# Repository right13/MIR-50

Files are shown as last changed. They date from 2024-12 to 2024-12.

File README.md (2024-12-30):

I re-designed back in 2012 and old amplifier design published in one of the local magazines for radio amateurs in 1992. The goal was to adapt it to modern (back in 2012) semiconductors and redesign the PCB for DIY audio community in the country.
There is not too much description: I couldnt find the original text. 
 I, with a few other guys managed to sell a few hundreds pcs of the kit and also I made probably another 100 pcs at home by myself. It works as a charm after first powering. Some guys used it as headphone amplifier. 

Some parameters:
Power transistors : TOSHIBA 2SC5200/2SA1943
 Exciters : 2SA1837/2CS4792 or 2SA1930/2SC5171
Pre-amplifier : BD139/140 
Differential stage : BC550/560
Power supply : 2x30V DC 4R 
Output power : 56W
Minimum load impedance : 4R Input sensitivity 
: approx. 1 -1.3V@56W SR waveform speed : 52V/us
Fuses : F2,5A 
Dimension - 130x115 mm
Quiescent current on fuses approx. 120mA (on emitter resistors approx. 13-26mV)

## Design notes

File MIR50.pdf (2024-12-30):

## Nízkofrekvenčný tranzistorový zosilňovač

# MIR50

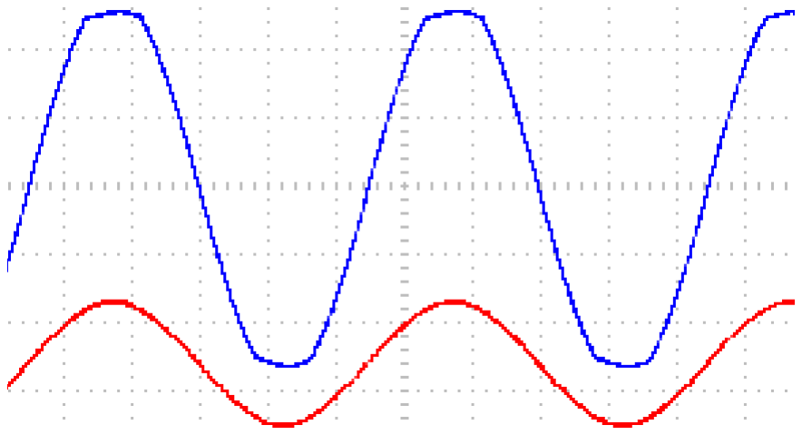
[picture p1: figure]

Autor pôvodného zapojenia : Pavel Dudek

Technický poradca úprav : Bc.Robert Kovář

Autor DPS a realizátor : Martin Krchňák

Distribúcia DPS a doplnkov : Petr Matušek

### Popis

Schéma zapojenia vychádza zo zapojenia DPA110 ktoré navrhol pán Dudek . V pôvodnom zapojení sú použité súčiastky dostupné v dobe vzniku, no na dnešnú dobu zastaralé a zle dostupné. Zapojenie MIR50 je prispôsobené na moderné bežne dostupné súčiastky s lepšími parametrami, čím sa podarilo dosiahnuť výborné výsledky po elektrickej aj po zvukovej stránke .

Tento dokument je príloha ku zakúpeným DPS .

Osadenie

Koncové tranzistory : TOSHIBA 2SC5200/2SA1943

Budiče : 2SA1837/2CS4792 alebo 2SA1930/2SC5171

Predbudič a rozkmit : BD139/140

Diferenčný stupeň : BC550/560

Parametre

Napájanie : 2x30V DC

Výstupný výkon 4R : 56W

Minimálna zaťažovacia impedancia : 4R

Vstupná citlivosť : cca 1 ‐1,3V@56W

Rýchlosť priebehu SR : 52V/us

Poistky : F2,5A

Rozmer ‐ 130x115 mm

### Zoznam súčiastok

Rezistory

4 | 0R | R, R67, R74, R75
12 | 1R/1W | R42, R43①, R44, R45,
| | R46, R47①, R48, R49, R61, R62, R54, R55
2 | 4R7/2W | R59, R60
9 | 10R | R12③, R50②, R56②, R57②, R58②.
| | R52, R53, R68, R69
4 | 39R | R27, R28, R33, R34
2 | 47R | R40, R41
9 | 100R | R3, R4, R5, R6, R32, R15, R16, R29, R51
2 | 150R | R37, R38
6 | 220R | R19, R20, R24, R39, R63, R23
1 | 470R | R13
1 | 680R | R31
2 | 1k | R17, R18
1 | 1k2 | R1
2 | 1K5 | R9, R10
3 | 1k8 | R30, R35, R36
4 | 2k2 | R7, R8, R21, R22
1 | 3k3 | R11
2 | 11k | R25, R25
2 | 47k | R2, R26
1 | 1M | R14
1 | T67W-5K | P2
1 | T67W-50K | P1

Polovodiče

1 | 2SA1943 | U$1
1 | 2SC5200 | U$2
1 | 2SA1837 | T21
1 | 2SC4793 | T25
2 | 4V7 /1,3W zenerová dioda | D7, D8
2 | 15V /1,3W zenerová dioda | D1, D2
4 | BAV21 | D3, D5, D9, D10
2 | 1N4148 | D11, D12
5 | BC546 | T1, T2, T3, T7, T13
5 | BC556 | T4, T5, T6, T8, T14
1 | BC558 | T12
3 | BD139 | T10, T11, T15
2 | BD140 | T9, T16
2 | BY299 | D20, D21
2 | červená 5mm | LED1, LED2

Kondenzátory

3 | 1µF | | C1, C16, C22
2 | 1nF | | C8, C9
2 | 2p7 | | C10, C11
2 | 10nF | | C17, C18
2 | 22pF⑤ | | C25, C26
2 | 47nF | 10mm | C19, C20
10 | 100nF | | C3, C24, C27, C29, C31, C32, C33, C34, C35, C15
8 | 100uF/50V | | C6, C7, C12, C13, C19, C21, C23, C30
2 | 100uF/25V | | C4, C5
1 | 220pF | | C2
1 | 2p7/3p3④

*pokial nie je napísané ináč C majú raster 5mm

Mechanické prvky

1 | PSH02-02P | K1
6 | faston ST4,8 | X1, X2, X3, X4, X5, X6
2 | 2,5A | F1, F2

Pozn.

① neosadzovať ,v emitoroch použiť iba 4ks 1R/1W

②Osadiť buď 4x 10R/1W alebo 2x4R7/2W

③Možné nahradiť prepojkou

④Osadiť podla budičov, pre 2SA1837/4793 použiť 2p7 , pre 2SA1930/2SC5171 3p3

⑤Osadiť v prípade nestability

### Schéma zapojenia

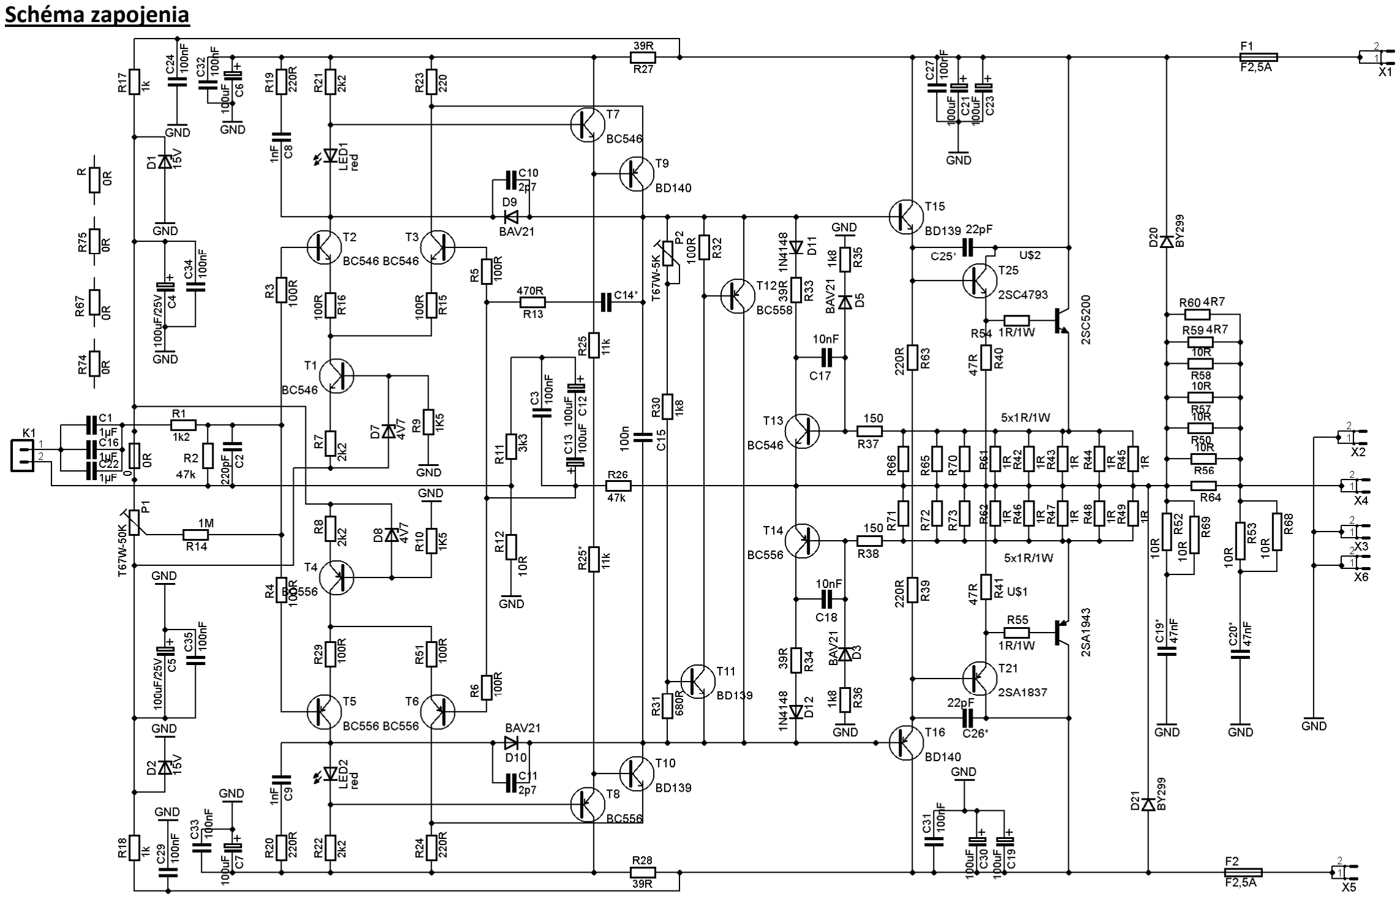
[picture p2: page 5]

### Osadzovací plán

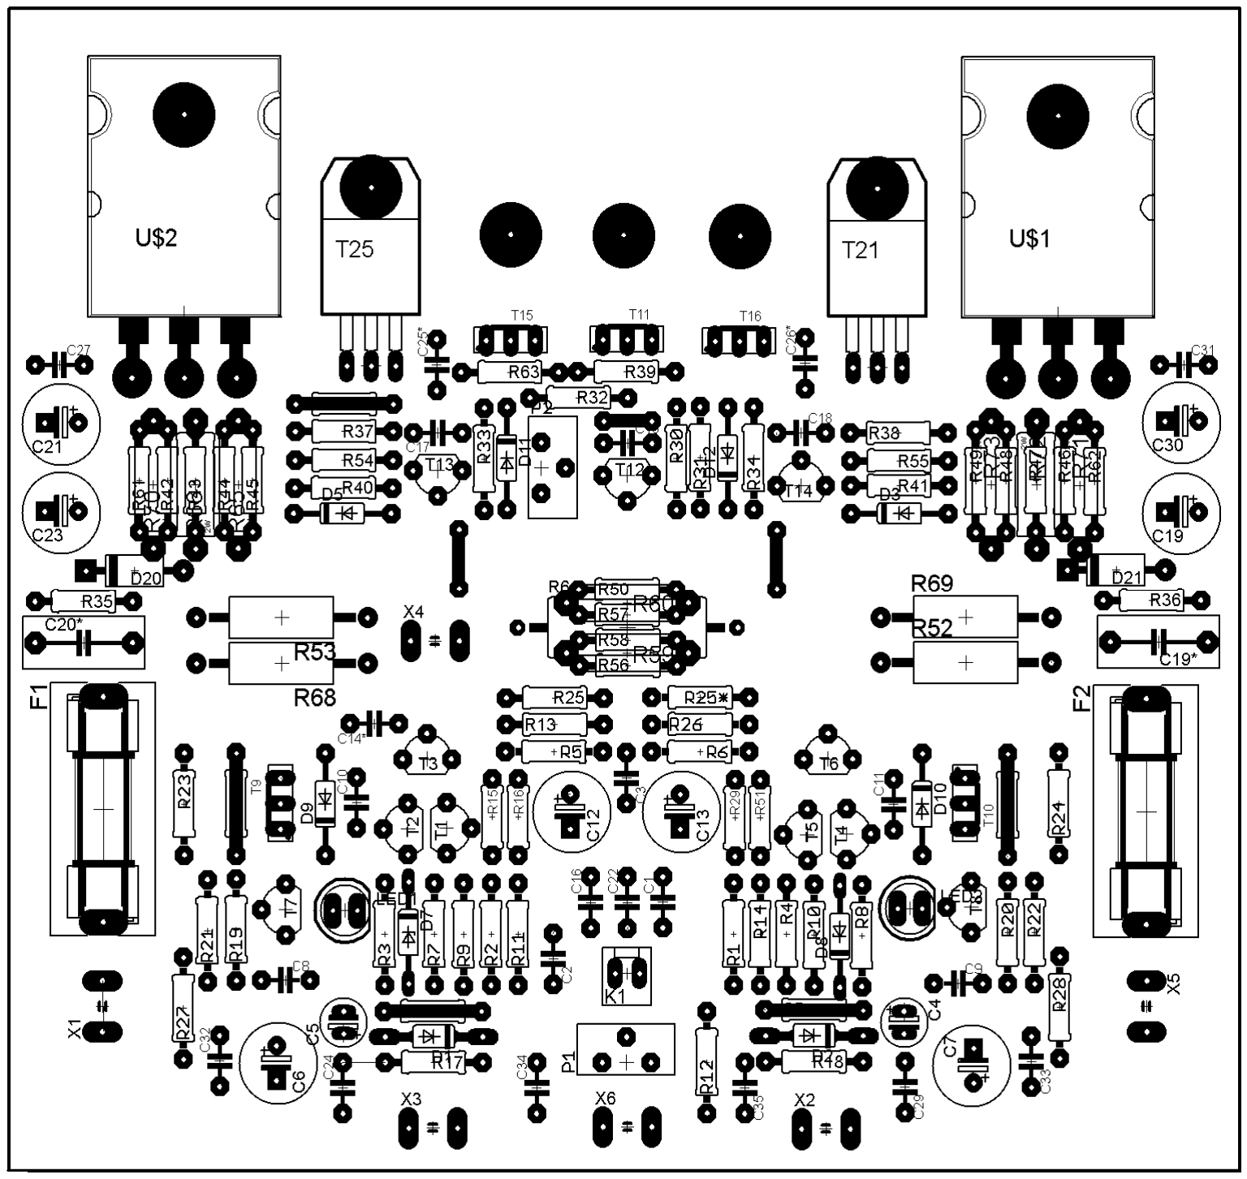
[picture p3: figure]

### Výkres AL profilu

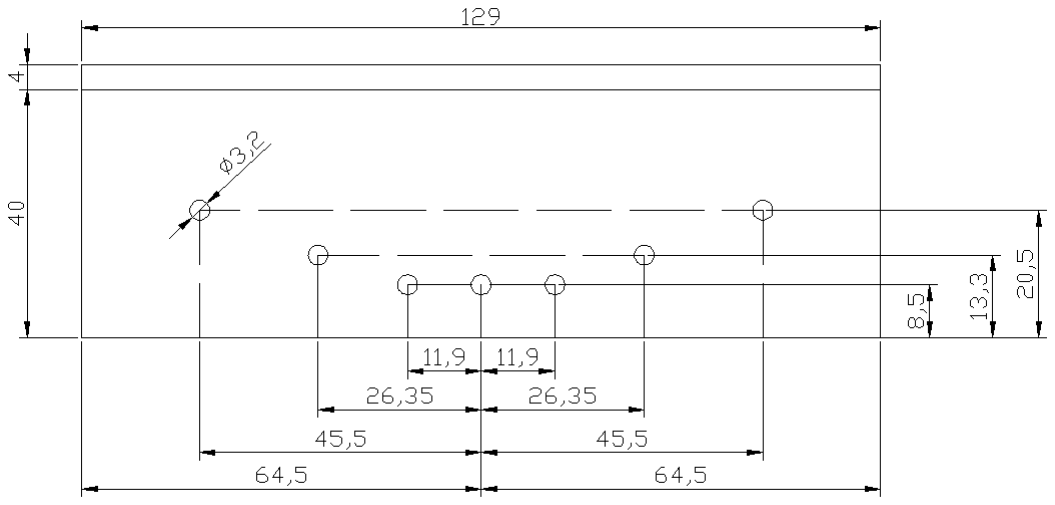
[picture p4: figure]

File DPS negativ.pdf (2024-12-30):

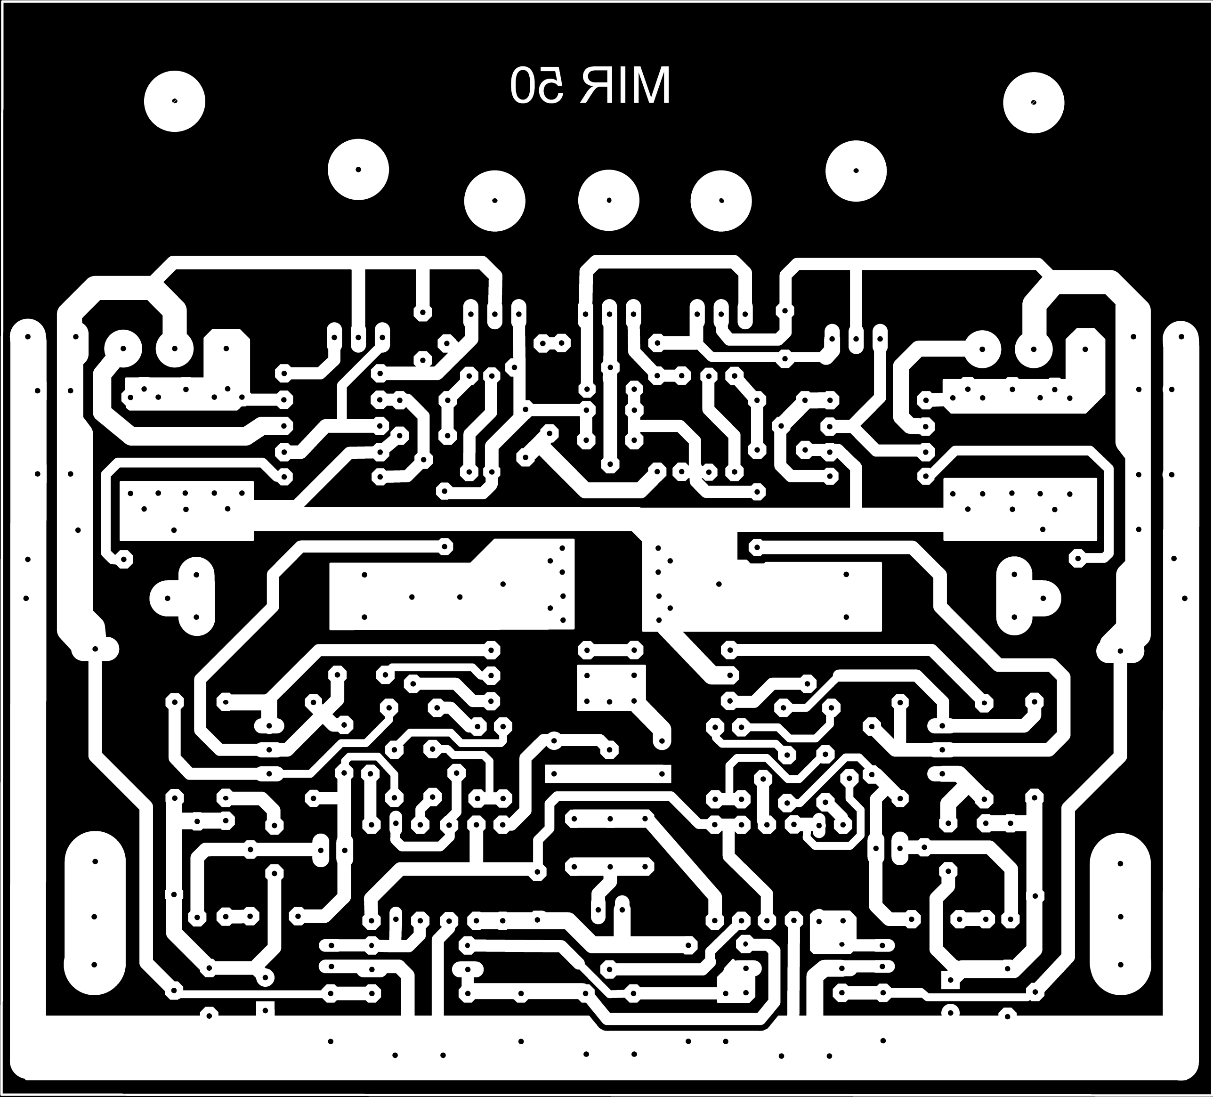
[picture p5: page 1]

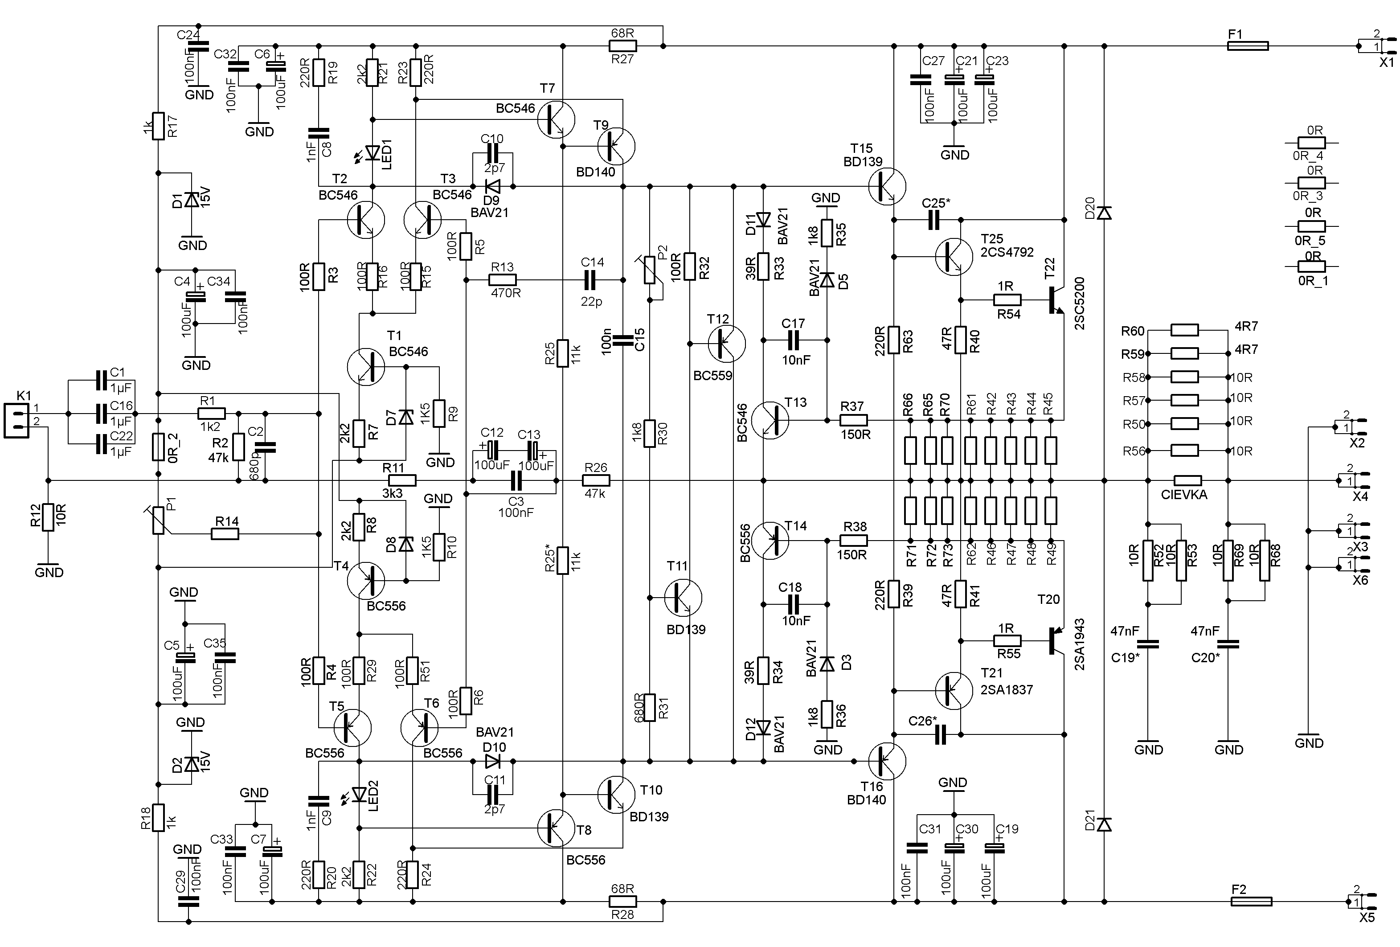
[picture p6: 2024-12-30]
schema.png

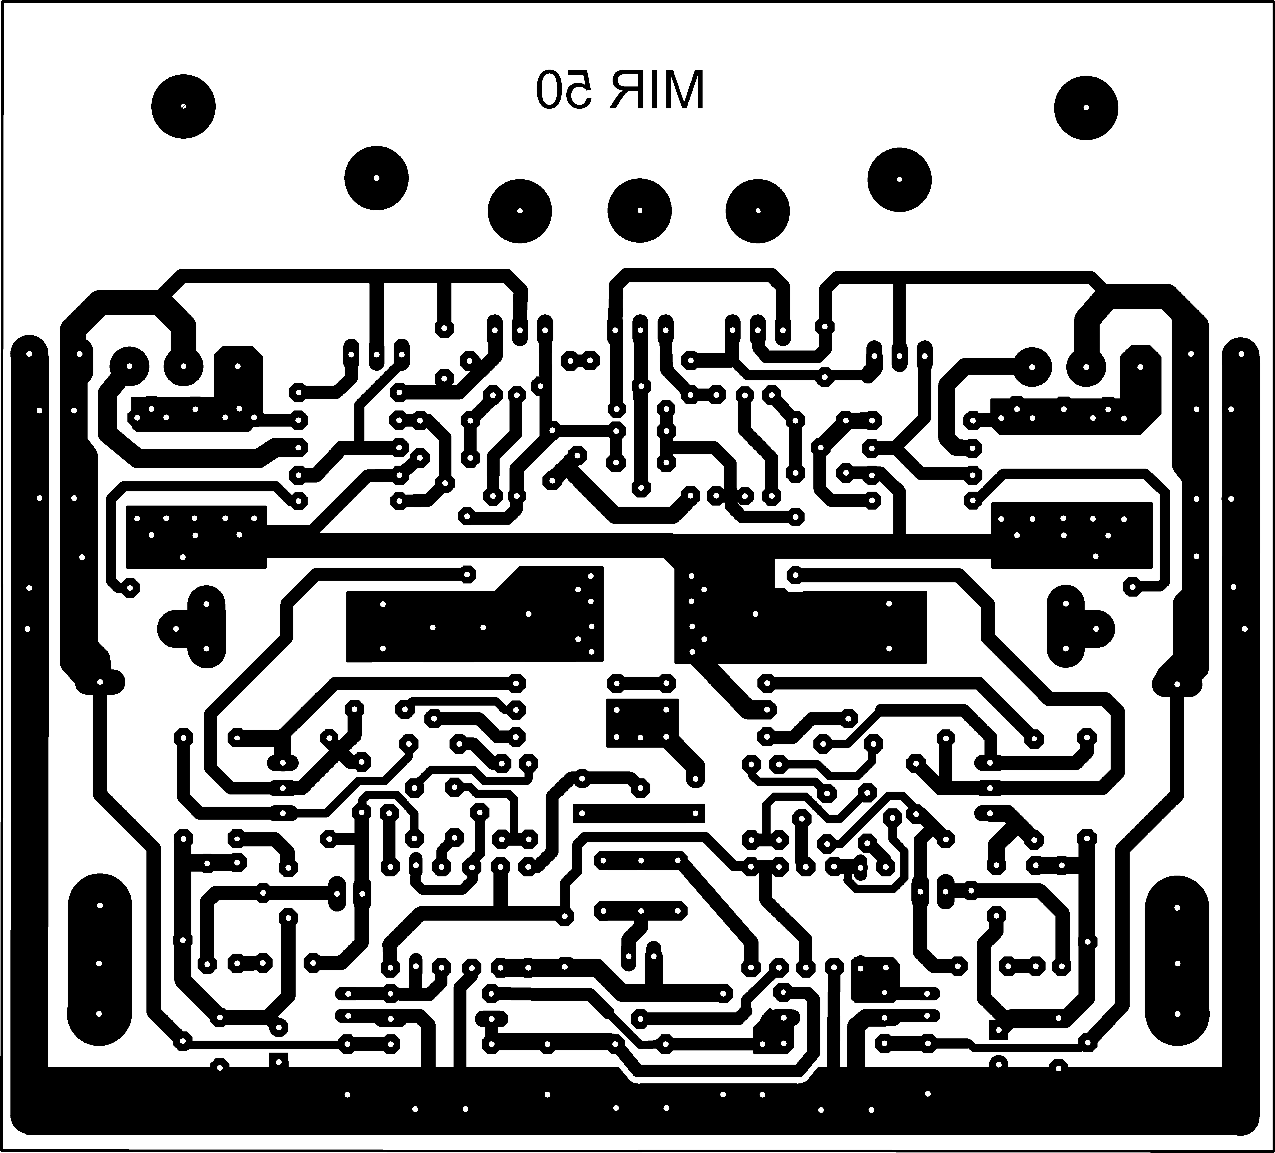
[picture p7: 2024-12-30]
DPS pozitiv.png

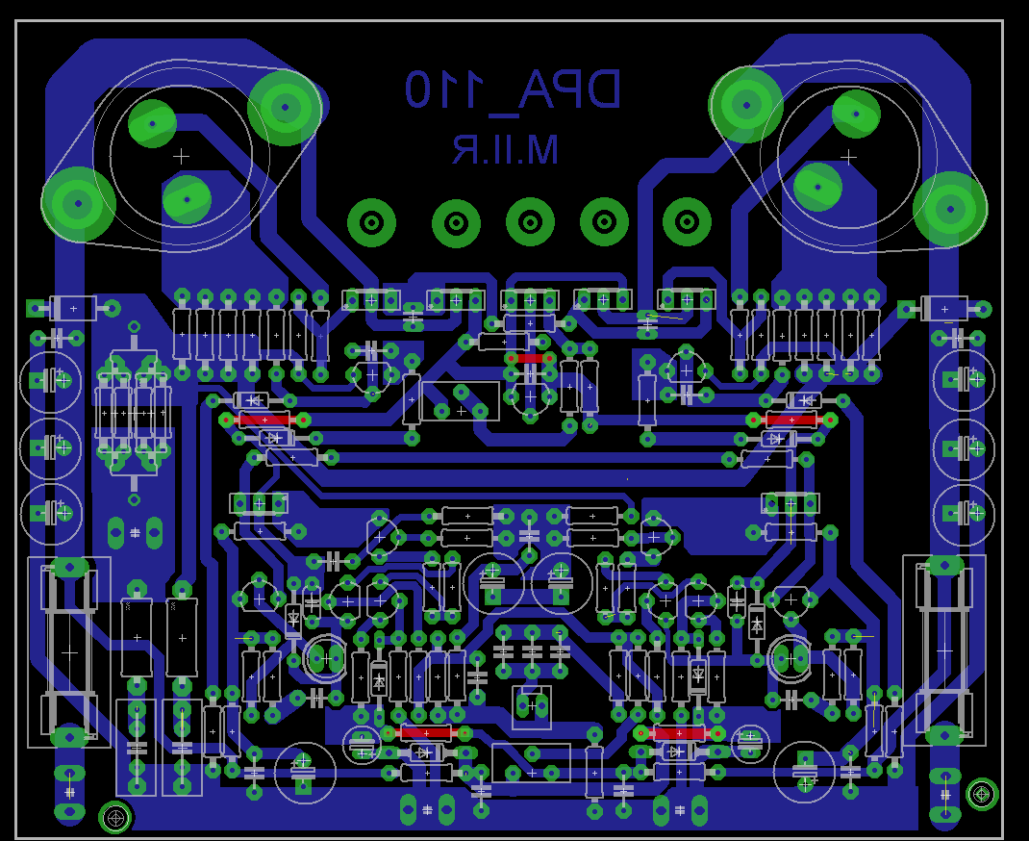
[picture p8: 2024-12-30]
board.png

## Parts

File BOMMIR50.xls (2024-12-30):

 | No | Value | Resistors
Qty Value Device Parts | 1 | PSH02-02P | 5 | 0R
1 PSH02-02P K1 | 1 | CIEVKA | 2 | 1K5
1 R-EU_0617/22 CIEVKA | 6 | faston 4,8 + fastin | 1 | 1M
6 R__2W R65, R66, R70, R71, R72, R73 | 2x fuse holder |  | 2 | 1k
6 ST4,8 X1, X2, X3, X4, X5, X6 |  |  | 1 | 1k2
1 0 R_10 0R |  |  | 3 | 1k8
4 0R R_10 R, R67, R74, R75 | semiconductors |  | 1 | 3k3
3 1µF C-KERAMIK_5 C1, C16, C22 | 2 | F2,5A-poistka | 2 | 11k
2 1K5 R_10 R9, R10 | 1 | 2SA1837 | 2 | 22R
1 1M R_10 R14 | 1 | 2SA1943 | 2 | 39R
10 1R R_10 R42, R43, R44, R45, R46, R47, R48, R49, R61, R62 | 1 | 2SC4793 | 2 | 47R
2 1R/1W R_10 R54, R55 | 1 | 2SC5200 | 2 | 47k
2 1k R_10 R17, R18 | 2 | 4V7 ZD | 9 | 100R
1 1k2 R_10 R1 | 2 | 15V-ZD | 2 | 150R
3 1k8 R_10 R30, R35, R36 | 6 | BAV21 | 6 | 220R
2 1nF C-KERAMIK_5 C8, C9 | 5 | BC546 | 1 | 470R
2 2,5A SH22,5A F1, F2 | 5 | BC556 | 1 | 680R
1 2SA1837 BD912_LEZ T21 | 1 | BC558 | 4 | 2k2
1 2SA1943 2SA1943 U$1 | 3 | BD139 | 4 | 20R/2W
1 2SC4793 BD711_LEZ T25 | 2 | BD140 | 2 | 4R7 /2W
1 2SC5200 2SC5200 U$2 | 2 | BY299 | 1 | T67W-5K
4 2k2 R_10 R7, R8, R21, R22 | 2 | red LED5MM | 1 | T67W-50K
2 2p7 C-KERAMIK_5 C10, C11 |  |  | 10 | 1R/1W
1 3k3 R_10 R11 |  |  | 6 | R__2W
2 4R7 R__2W R59, R60
2 4V7 BZX55 D7, D8 | capacitors
4 10R RAC01 R52, R53, R68, R69 | 3 | 1µF MKT
5 10R R_10 R12, R50, R56, R57, R58 | 2 | 1nF
2 10nF C-KERAMIK_5 C17, C18 | 2 | 2p7
2 11k R_10 R25, R25* | 2 | 10nF
2 15V BZD23 D1, D2 | 1 | 22p
2 22R R_10 R27, R28 | 2 | 22pF ***
1 22p C-KERAMIK_5 C14 | 10 | 100nF
2 22pF C-KERAMIK_5 C25*, C26* | 8 | 100uF/50V
2 39R R_10 R33, R34 | 2 | 100uF/25V
2 47R R_10 R40, R41 | 1 | 220pF
2 47k R_10 R2, R26 | 2 | 470nF
4 100R R_7,5 R15, R16, R29, R51
5 100R R_10 R3, R4, R5, R6, R32
1 100n C-KERAMIK_5 C15
9 100nF C-KERAMIK_5 C3, C24, C27, C29, C31, C32, C33, C34, C35
8 100uF C-ELEKTROLYT_3,5 C6, C7, C12, C13, C19, C21, C23, C30
2 100uF/25V C-ELEKTROLYT_2 C4, C5
2 150 R_10 R37, R38
1 220 R_10 R23
5 220R R_10 R19, R20, R24, R39, R63
1 220pF C-KERAMIK_5 C2
1 470R R_10 R13
2 470nF C-KERAMIK_10 C19*, C20*
1 680R R_10 R31
6 BAV21 BAV21 D3, D5, D9, D10, D11, D12
5 BC546 BC546 T1, T2, T3, T7, T13
5 BC556 BC556 T4, T5, T6, T8, T14
1 BC558 BC559 T12
3 BD139 BD139 T10, T11, T15
2 BD140 BD140 T9, T16
2 BY299 D_10 D20, D21
1 T67W-5K TRIMR64Y P2
1 T67W-50K TRIMR64Y P1
2 red LED5MM LED1, LED2

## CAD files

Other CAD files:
Lmount.dwg

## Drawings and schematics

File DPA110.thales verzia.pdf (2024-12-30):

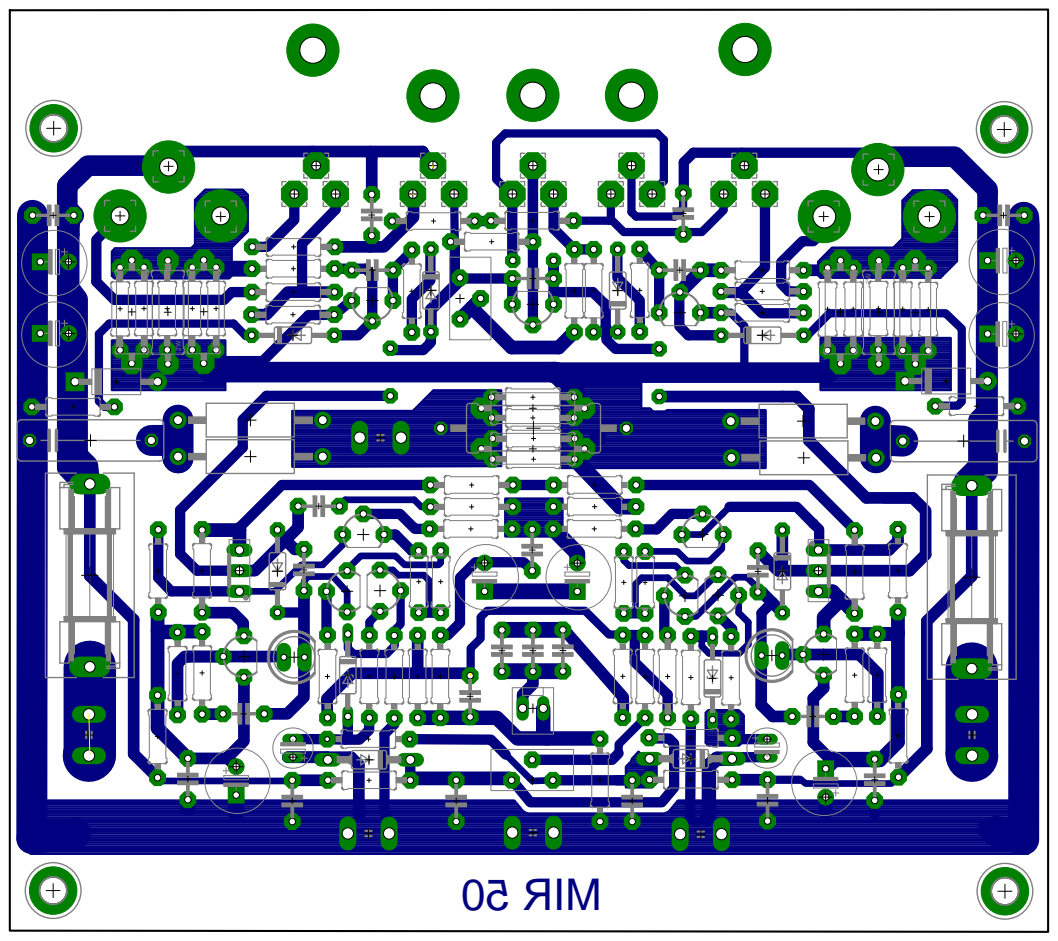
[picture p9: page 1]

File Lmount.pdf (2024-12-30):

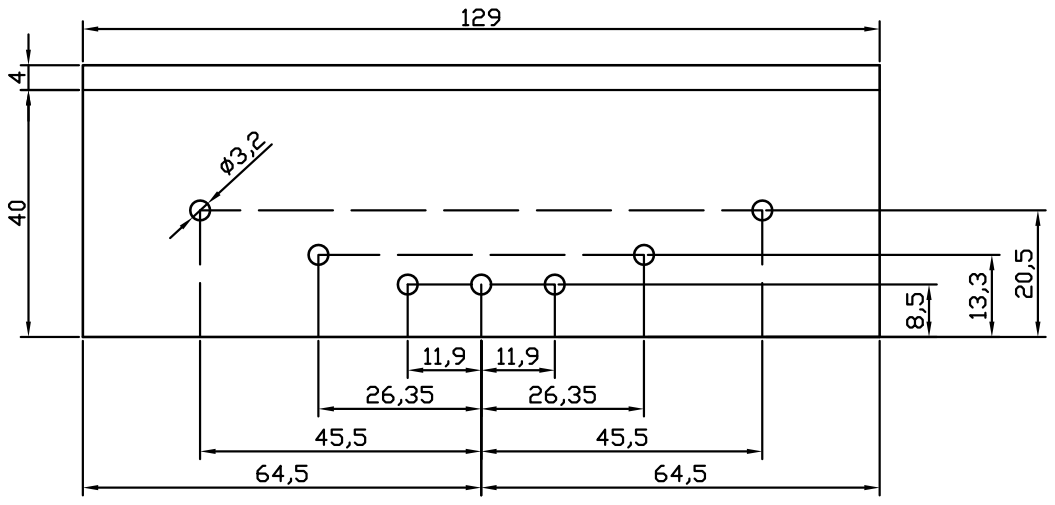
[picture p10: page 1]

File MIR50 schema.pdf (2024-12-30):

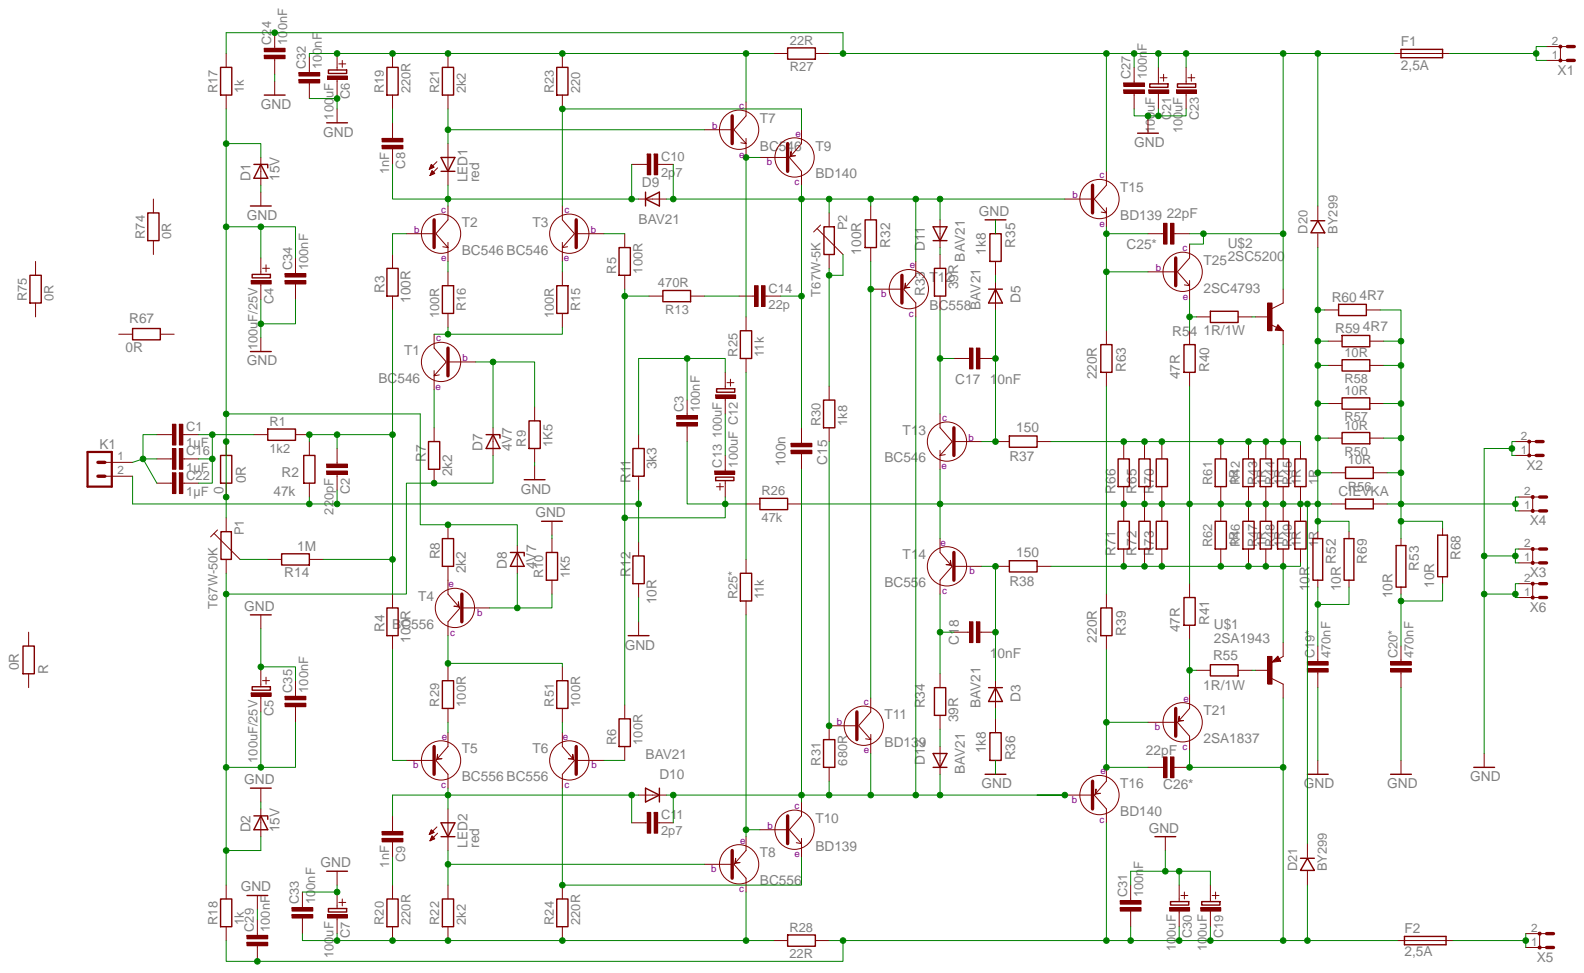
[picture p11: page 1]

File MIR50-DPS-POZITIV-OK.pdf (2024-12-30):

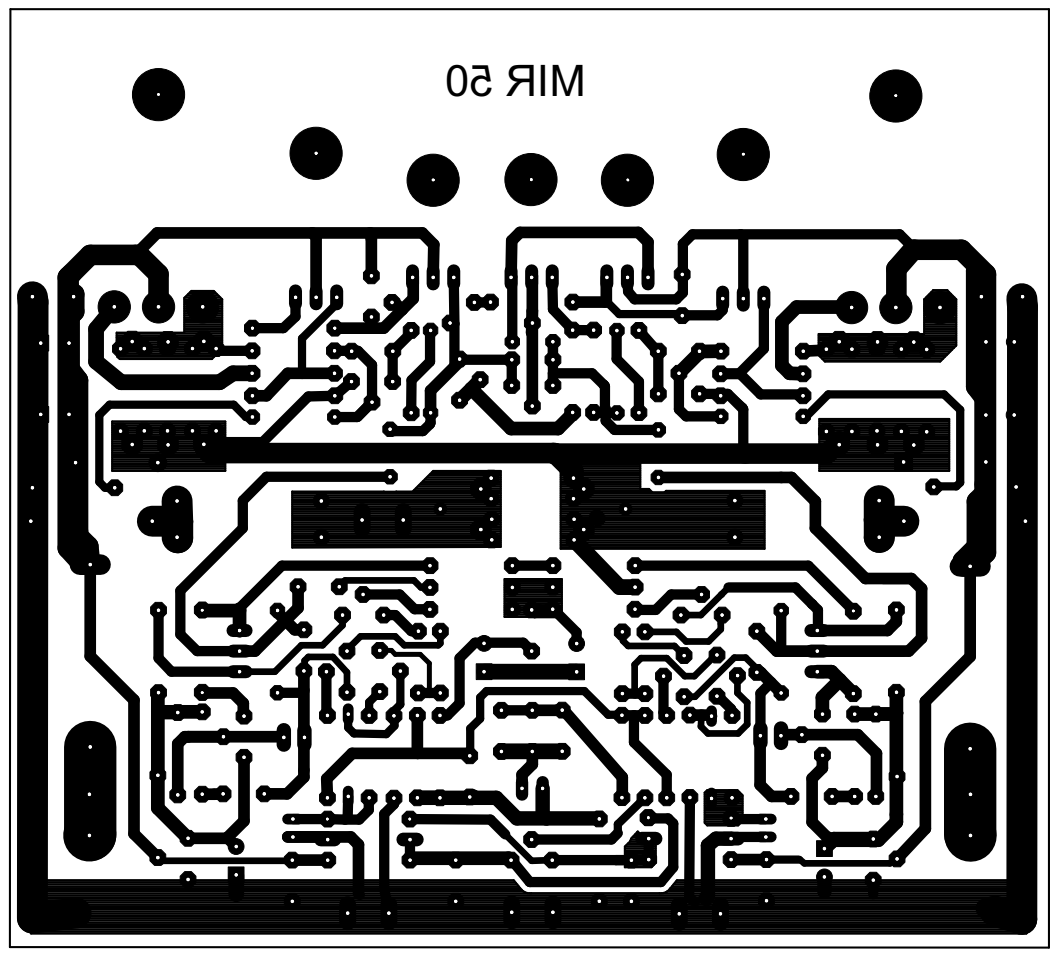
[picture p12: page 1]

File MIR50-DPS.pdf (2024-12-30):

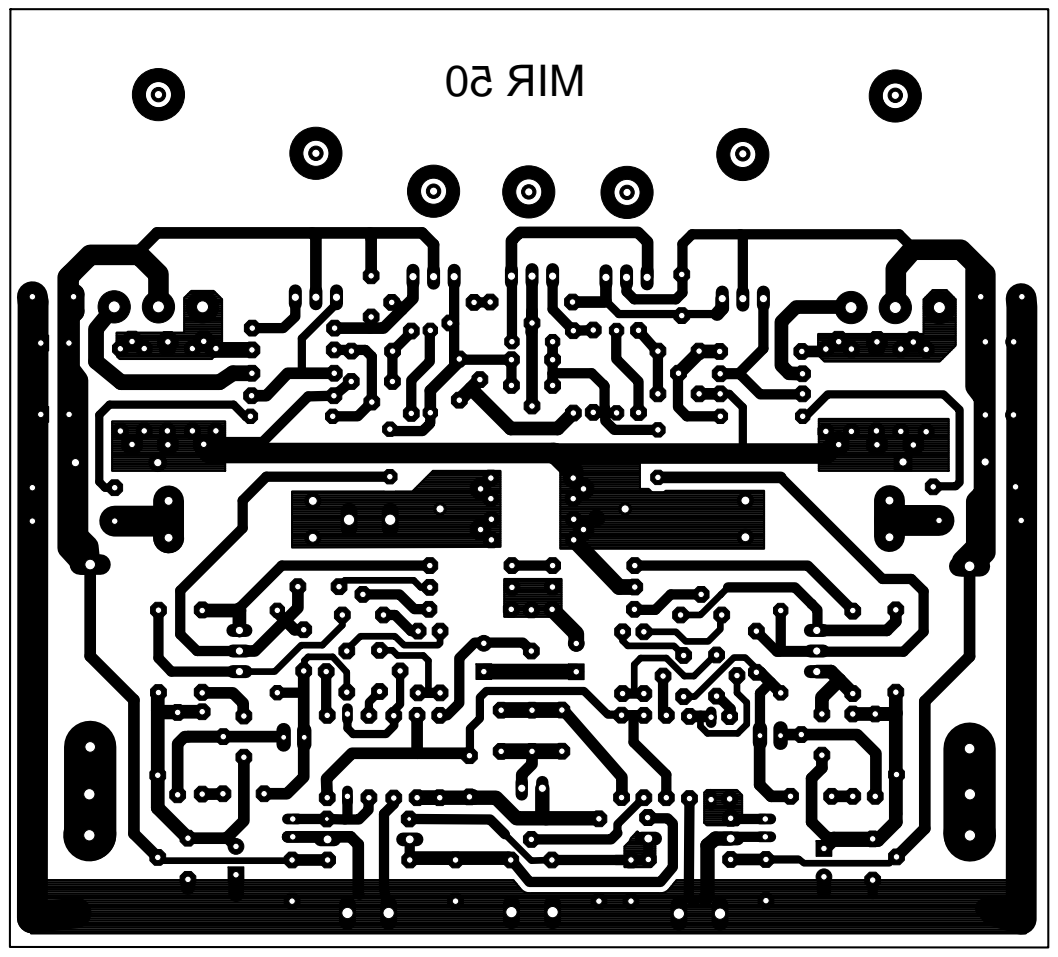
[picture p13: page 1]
MIR 50

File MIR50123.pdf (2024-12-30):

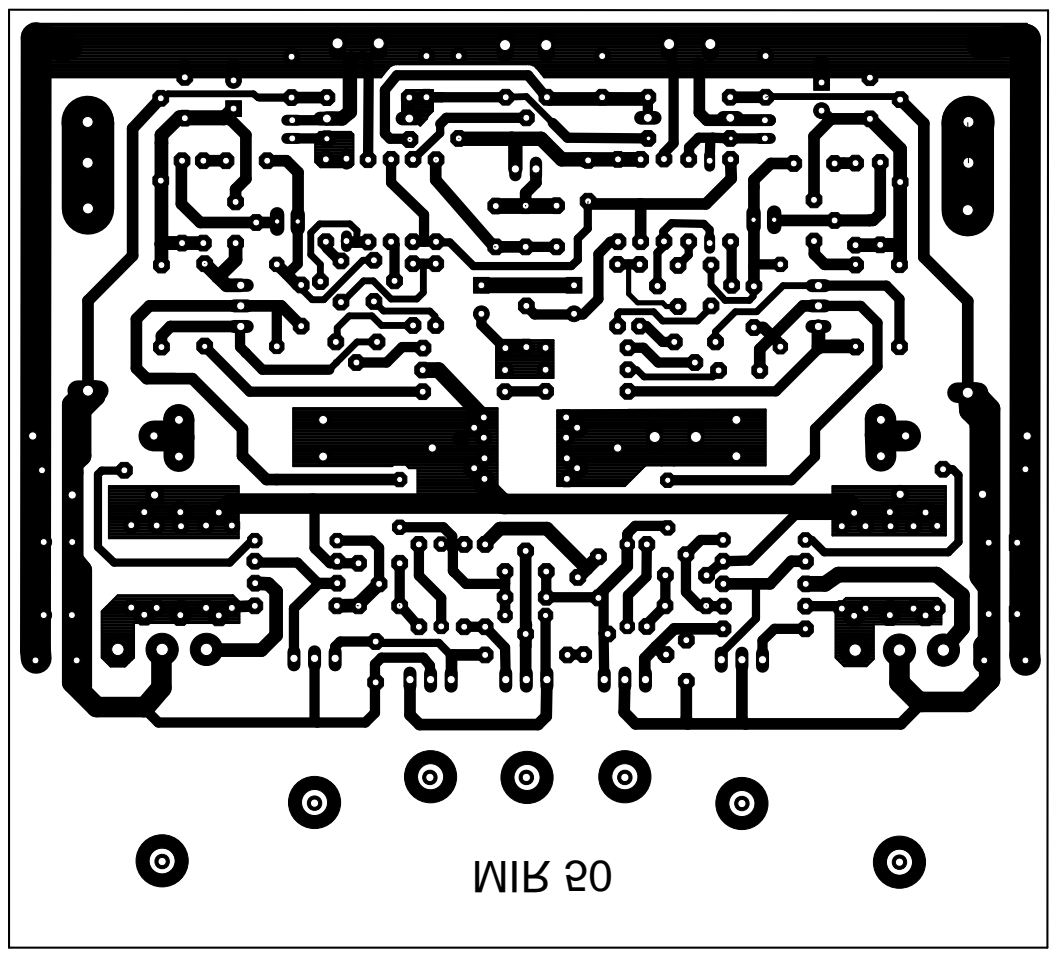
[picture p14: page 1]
MIR 50

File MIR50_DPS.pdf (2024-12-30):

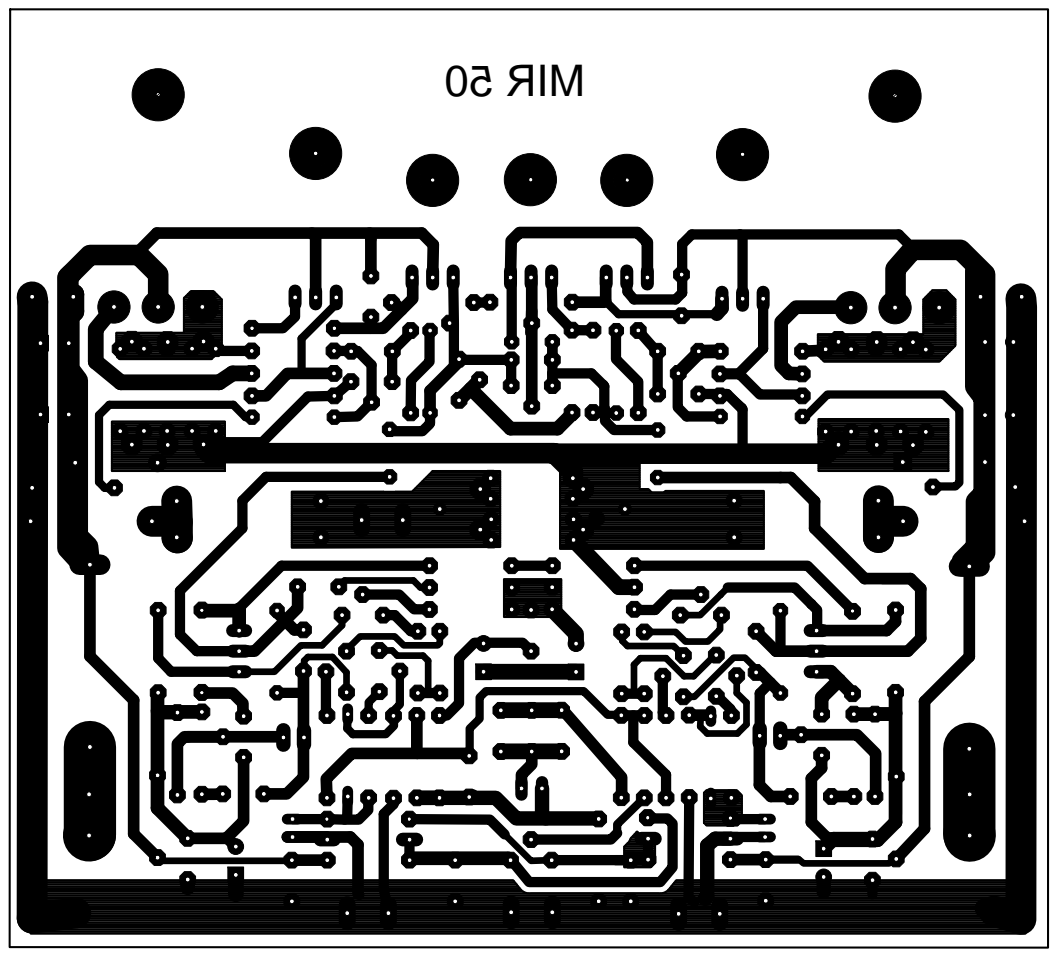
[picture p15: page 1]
MIR 50

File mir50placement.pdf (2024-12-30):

U$2 | U$1
T25 | T21

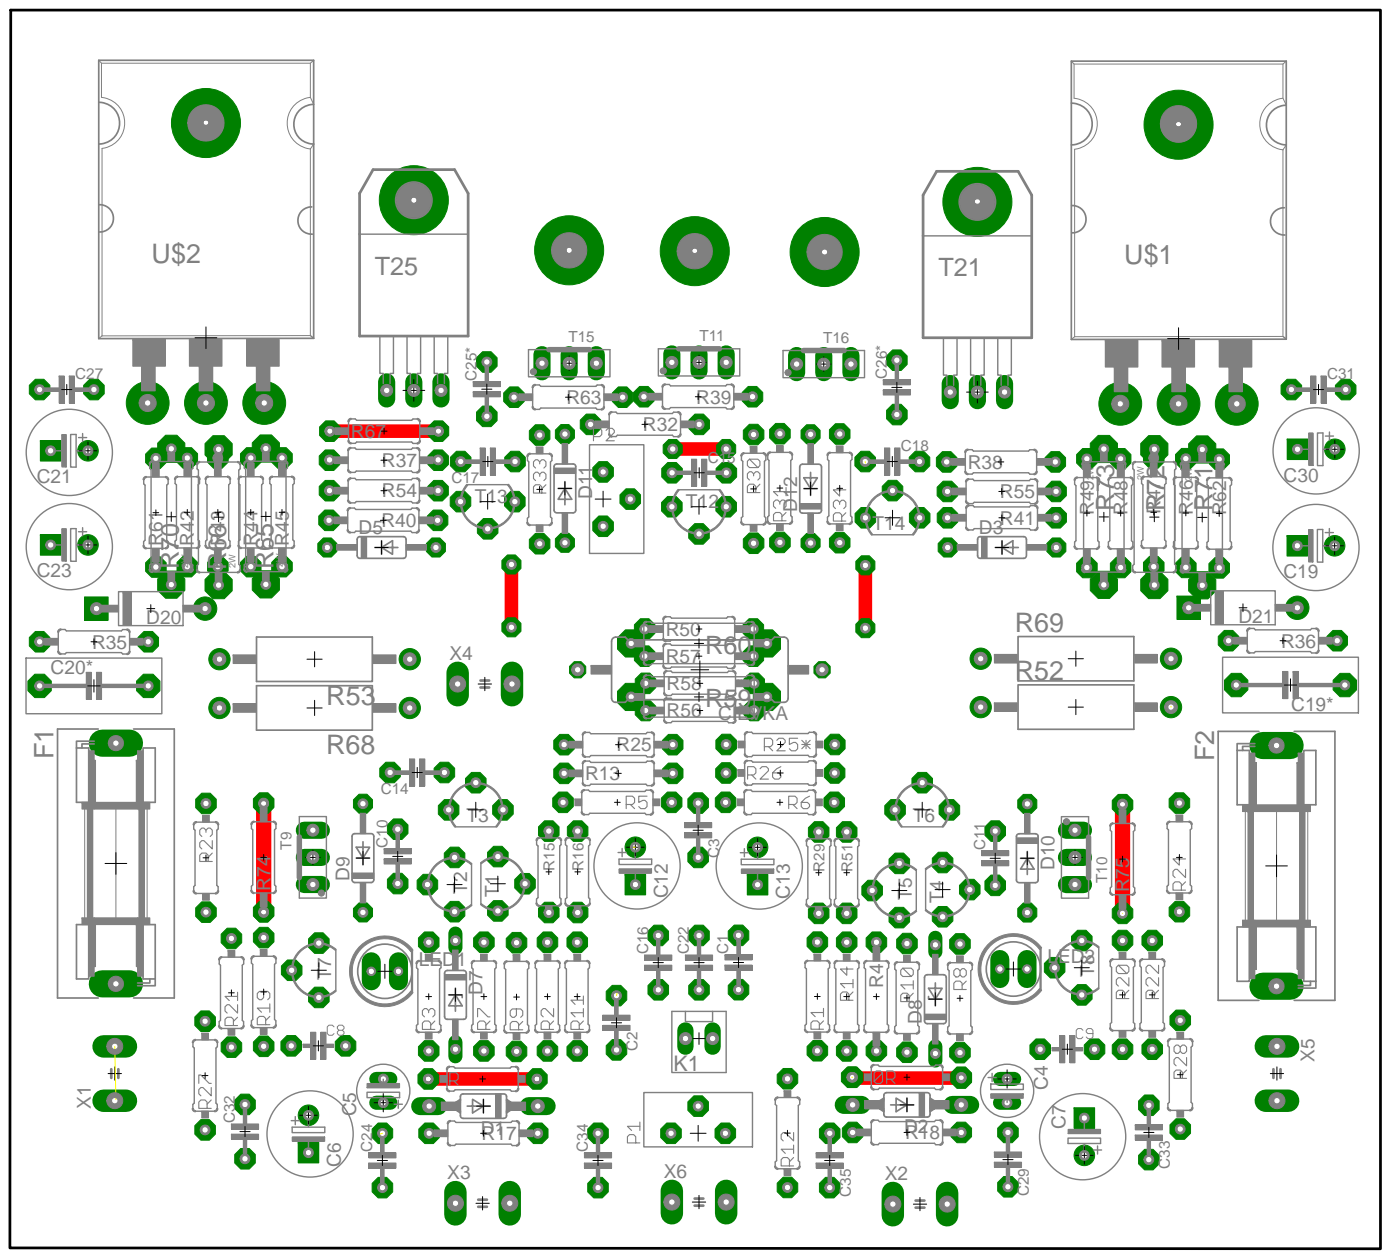
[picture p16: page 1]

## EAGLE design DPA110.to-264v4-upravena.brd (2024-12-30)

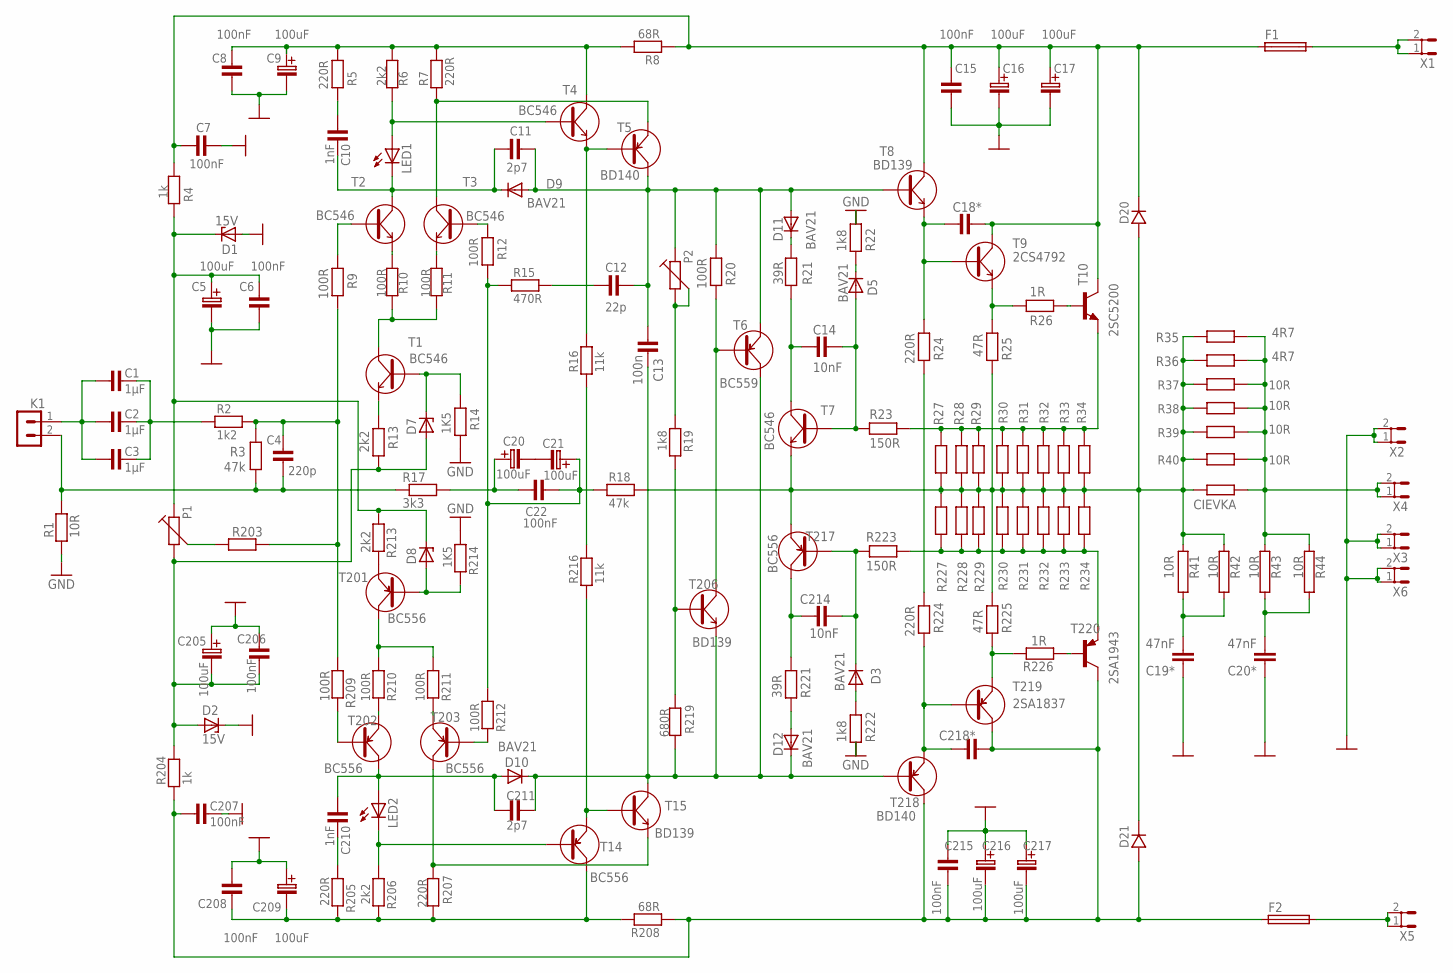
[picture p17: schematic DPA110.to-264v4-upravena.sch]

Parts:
C1, C2, C3: 1µF; C-5
C4: 220p; C-5
C5, C205: 100uF; C-EL_2
C6, C7, C8, C15, C22, C206, C207, C208, C215: 100nF; C-5
C9, C16, C17, C20, C21, C209, C216, C217: 100uF; C-EL_3,5
C10, C210: 1nF; C-5
C11, C211: 2p7; C-5
C12: 22p; C-5
C13: 100n; C-5
C14, C214: 10nF; C-5
C18*, C218*: C-KERAMIK_5; C-5
C19*, C20*: 47nF; C150-054X183
CIEVKA: 10R; 0617/22
D1, D2: 15V; SOD81
D3, D5, D9, D10, D11, D12: BAV21; DO35-10
D7, D8: BZX55; DO35Z10
D20, D21: D_10; DO41
F1, F2: SH22,5A
K1: PSH02-02P
LED1, LED2: LED5MM
P1, P2: TRIMR64Y; 64Y
R1, R37, R38, R39, R40: 10R; R-10
R2: 1k2; R-10
R3, R18: 47k; R-10
R4, R204: 1k; R-10
R5, R7, R24, R205, R207, R224: 220R; R-10
R6, R13, R206, R213: 2k2; R-10
R8, R208: 68R; R-10
R9, R12, R20, R209, R212: 100R; R-10
R10, R11, R210, R211: 100R; R-7,5
R14, R214: 1K5; R-10
R15: 470R; R-10
R16, R216: 11k; R-10
R17: 3k3; R-10
R19, R22, R222: 1k8; R-10
R21, R221: 39R; R-10
R23, R223: 150R; R-10
R25, R225: 47R; R-10
R26, R226: 1R; R-10
R27, R28, R29, R227, R228, R229: R__2W; R-_2W
R30, R31, R32, R33, R34, R203, R230, R231, R232, R233, R234: R_10; R-10
R35, R36: 4R7; R-_2W
R41, R42, R43, R44: 10R; AC01
R219: 680R; R-10
T1, T2, T3, T4, T7: BC546; TO-92
T5: BD140; TO-126S
T6: BC559; TO-92
T8, T206: BD139; TO-126
T9: 2CS4792; TO-220
T10: 2SC5200; TO-264
T14, T201, T202, T203, T217: BC556; TO-92
T15: BD139; TO-126S
T218: BD140; TO-126
T219: 2SA1837; TO-220
T220: 2SA1943; TO-264
X1, X2, X3, X4, X5, X6: ST4,8

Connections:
AERT?ZQA??: R16.1, R216.2
D7*: D8.A, R214.2, T201.2 (B)
GND: C5.C- (C_EL-), C6.1, C7.1, C8.1, C9.C- (C_EL-), C15.1, C16.C- (C_EL-), C17.C- (C_EL-), C19*.1, C20*.1, C205.C+ (C_EL+), C206.2, C207.2, C208.2, C209.C+ (C_EL+), C215.2, C216.C+ (C_EL+), C217.C+ (C_EL+), D1.A, D2.C, R1.1, R14.1, R22.2, R214.1, R222.1, X2.1, X2.2, X3.1, X3.2, X6.1, X6.2
unnamed: C1.2, C2.2, C3.2, R2.1
unnamed: C218*.1, R224.1, T218.1 (E), T219.1 (B)
unnamed: C4.2, K1.2, R1.2, R3.1, R17.1
unnamed: R13.2, T1.3 (E)
unnamed: C4.1, R2.2, R3.2, R9.1, R203.2, R209.1
unnamed: R9.2, T2.2 (B)
unnamed: R10.2, T2.3 (E)
unnamed: D7.C, R14.2, T1.2 (B)
unnamed: C205.C- (C_EL-), C206.1, D2.A, D7.A, P1.2, R13.1, R204.2
unnamed: P1.3, R203.1
unnamed: R213.2, T201.3 (E)
unnamed: R209.2, T202.2 (B)
unnamed: R210.2, T202.3 (E)
unnamed: R12.2, T3.2 (B)
unnamed: D5.C, R22.1
unnamed: R212.2, T203.2 (B)
unnamed: C7.2, C15.2, C16.C+ (C_EL+), C17.C+ (C_EL+), C18*.2, D20.K, F1.1, R4.2, R8.1, T8.2 (C), T9.2 (C), T10.C
unnamed: C21.C+ (C_EL+), C22.1, R12.1, R15.1, R18.1, R212.1
unnamed: C20.C- (C_EL-), C21.C- (C_EL-)
unnamed: C8.2, R5.2, R6.2, R7.1, R8.2, T4.1 (C)
unnamed: C20.C+ (C_EL+), C22.2, R17.2
unnamed: C10.1, R5.1
unnamed: C10.2, C11.1, D9.C, LED1.K (C), T2.1 (C)
unnamed: LED2.K (C), R206.1, T14.2 (B)
unnamed: C19*.2, R41.2, R42.2
unnamed: C18*.1, R24.2, T8.1 (E), T9.1 (B)
unnamed: LED1.A, R6.1, T4.2 (B)
unnamed: C210.2, R205.1
unnamed: R7.2, T3.1 (C), T5.1 (E)
unnamed: C208.1, C209.C- (C_EL-), R205.2, R206.2, R207.1, R208.2, T14.1 (C)
unnamed: R207.2, T15.1 (E), T203.1 (C)
unnamed: R16.2, T4.3 (E), T5.3 (B)
unnamed: C12.1, R15.2
unnamed: C11.2, C12.2, C13.1, D9.A, D11.A, P2.1, R20.2, T5.2 (C), T6.3 (E), T8.3 (B)
unnamed: P2.2, P2.3, R19.1
unnamed: C13.2, C211.2, D10.C, D12.C, R219.1, T6.1 (C), T15.2 (C), T206.1 (E), T218.3 (B)
unnamed: R19.2, R219.2, T206.3 (B)
unnamed: R20.1, T6.2 (B), T206.2 (C)
unnamed: R11.2, T3.3 (E)
unnamed: C214.2, D3.C, R223.2, T217.2 (B)
unnamed: D11.C, R21.1
unnamed: C14.1, R21.2, T7.1 (C)
unnamed: D12.A, R221.1
unnamed: C214.1, R221.2, T217.1 (C)
unnamed: D3.A, R222.2
unnamed: C14.2, D5.A, R23.1, T7.2 (B)
unnamed: R10.1, R11.1, T1.1 (C)
unnamed: R24.1, R224.2
unnamed: R211.2, T203.3 (E)
unnamed: C207.1, C215.1, C216.C- (C_EL-), C217.C- (C_EL-), C218*.2, D21.A, F2.1, R204.1, R208.1, T218.2 (C), T219.2 (C), T220.C
unnamed: R210.1, R211.1, T201.1 (C)
unnamed: R25.2, R26.1, T9.3 (E)
unnamed: R225.1, R226.2, T219.3 (E)
unnamed: R23.2, R27.2, R28.2, R29.2, R30.2, R31.2, R32.2, R33.2, R34.2, T10.E
unnamed: R223.1, R227.1, R228.1, R229.1, R230.1, R231.1, R232.1, R233.1, R234.1, T220.E
unnamed: F1.2, X1.1, X1.2
unnamed: R26.2, T10.B
unnamed: F2.2, X5.1, X5.2
unnamed: R226.1, T220.B
unnamed: C210.1, C211.1, D10.A, LED2.A, T202.1 (C)
unnamed: CIEVKA.1, D20.A, D21.K, R18.2, R25.1, R27.1, R28.1, R29.1, R30.1, R31.1, R32.1, R33.1, R34.1, R35.1, R36.1, R37.2, R38.2, R39.2, R40.2, R41.1, R42.1, R225.2, R227.2, R228.2, R229.2, R230.2, R231.2, R232.2, R233.2, R234.2, T7.3 (E), T217.3 (E)
unnamed: R216.1, T14.3 (E), T15.3 (B)
unnamed: C5.C+ (C_EL+), C6.2, D1.C, D8.C, P1.1, R4.1, R213.1
unnamed: C20*.2, R43.2, R44.2
unnamed: C1.1, C2.1, C3.1, K1.1
OUT: CIEVKA.2, R35.2, R36.2, R37.1, R38.1, R39.1, R40.1, R43.1, R44.1, X4.1, X4.2

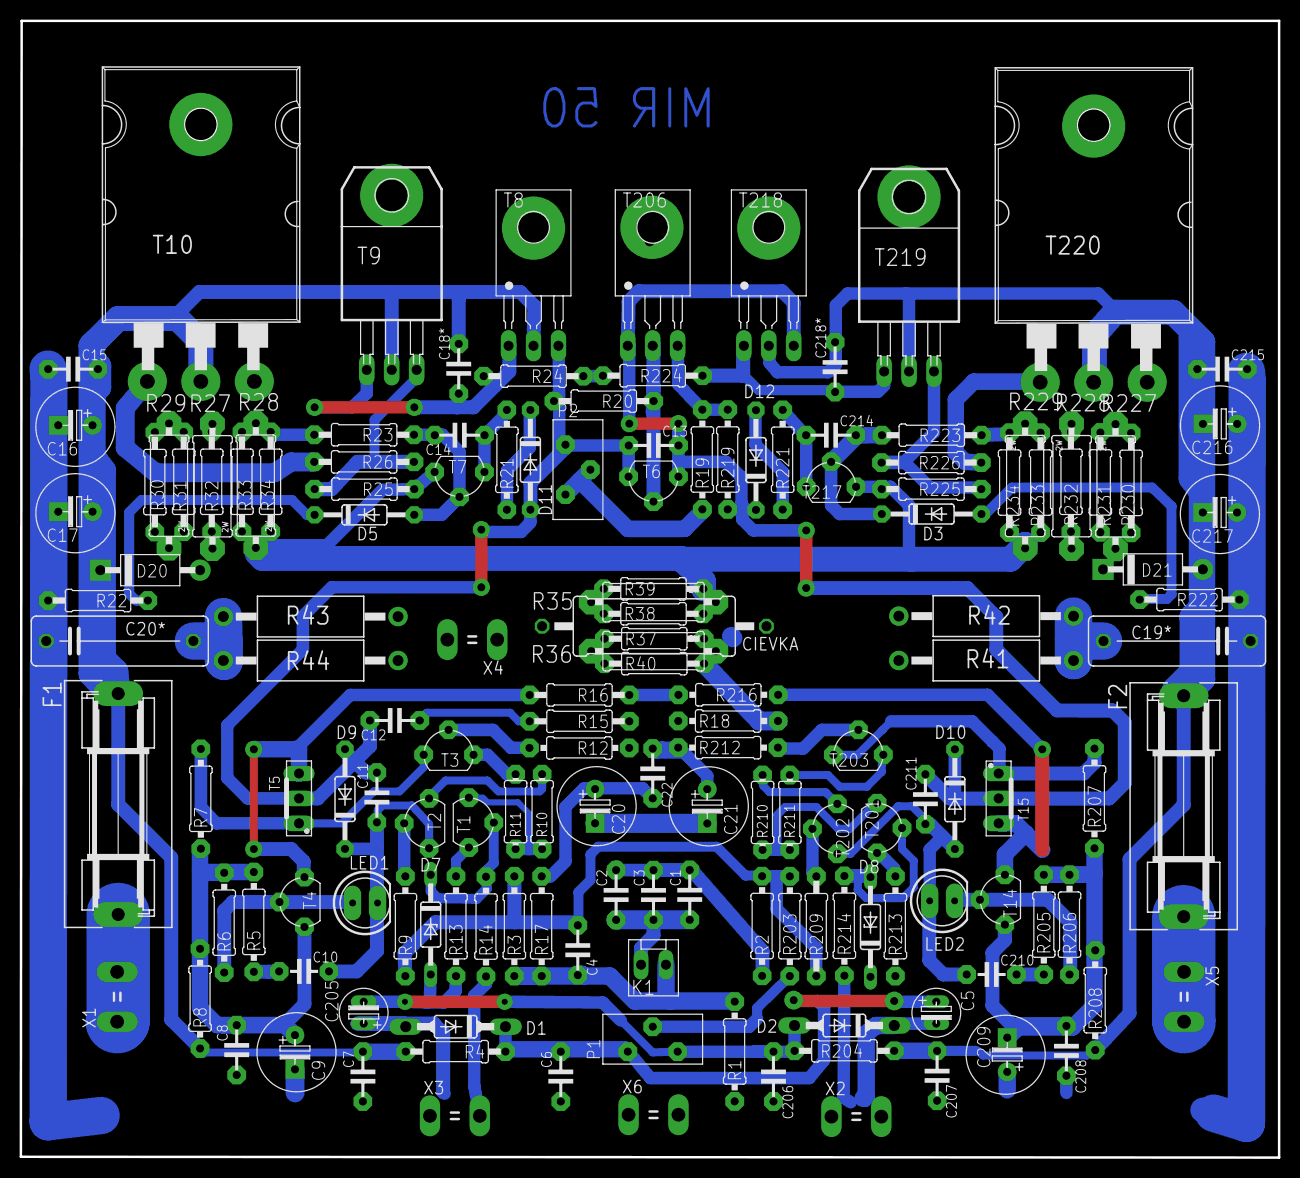
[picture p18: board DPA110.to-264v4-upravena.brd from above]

Board: 2 copper layers, 128.2 x 115.8 mm, 153 parts (0 on the bottom side), 69 nets.
